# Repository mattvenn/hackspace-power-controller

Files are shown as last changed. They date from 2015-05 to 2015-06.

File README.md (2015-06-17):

# Hackspace machine access & usage logger

A system for allowing inducted users to turn power on to various machines. 

* Users are authenticated with RFID.
* Usage time is logged to a [google spreadsheet](https://docs.google.com/spreadsheets/d/1C3qdswIIFLBH4fQWuWFZRTpnnRjpzyk5xHRKnjuHExU/edit?usp=sharing).
* Inducted users are managed using the same spreadsheet.
* Tools are turned on and off with wireless mains plugs.

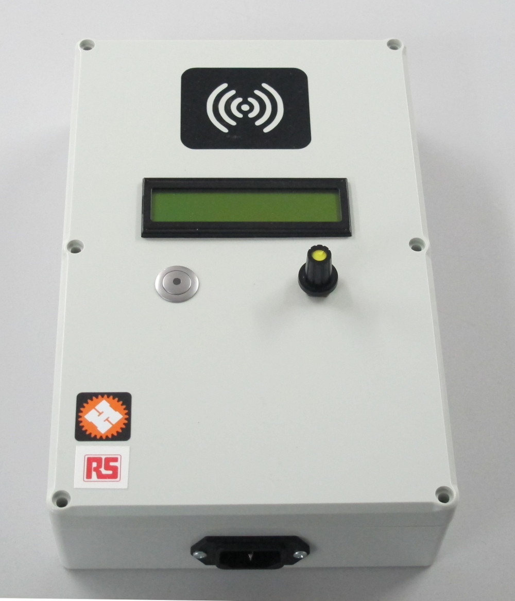
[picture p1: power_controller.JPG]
power controller


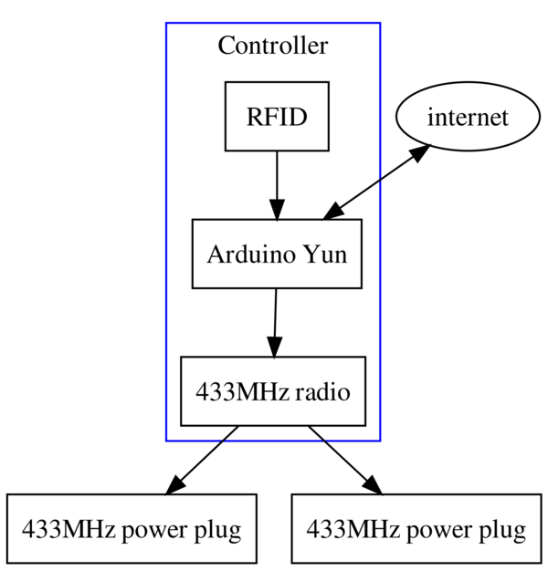
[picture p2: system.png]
system overview


Shortlink: [http://ven.nz/hkspcpc](http://ven.nz/hkspcpc)

Sponsored by [RS Components](http://uk.rs-online.com/web/)

## Pros

Cheap to implement as only need one central internet connected RFID reader and then very cheap
remote plugs for equipment.

Easy management for equipment managers via a google spreadsheet.

## Cons

Users will probably forget to 'log out' and clock up long machine run times.
Systems in use at [London
Hackspace](https://wiki.london.hackspace.org.uk/view/Project:Tool_Access_Control)
and [Nottingham Hackspace](https://wiki.nottinghack.org.uk/wiki/Nhtools) both
require the user's RFID card to remain in place while the machine is on, thus
making it less likely the user will leave the machine running.

Without covering/hacking the remote plugs; easy to bypass.

# Software

Split into:

* [Arduino code](software/power_controller/) for UI, RFID and radio. 
* [Python code](software/python/) for local caching, internet logging.

## Design decisions

* Presenting an inducted user's RFID card will authenticate.
* Simple menu system to scroll through available tools and start/stop them.
* Never switch off/time out the connected machine in case it's a long job.
* Allow an inducted user to end another user's session in case they left it
 running accidentally.
* Pull tools & validated users once per hour and store locally in case internet is unavailable.
* If internet is unavailable discard usage logging. Possible to add a queue later.

# Electrical

## Bill of Materials

See the [bom](electronics/bom.md)

## Schematic

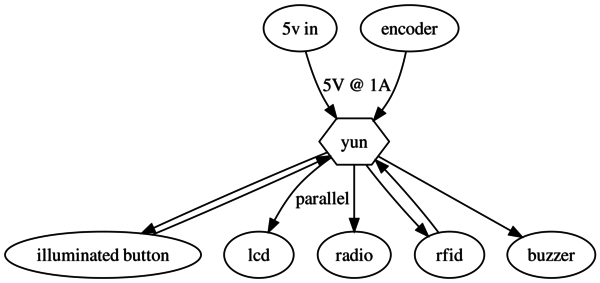
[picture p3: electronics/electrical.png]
electrical components and wiring


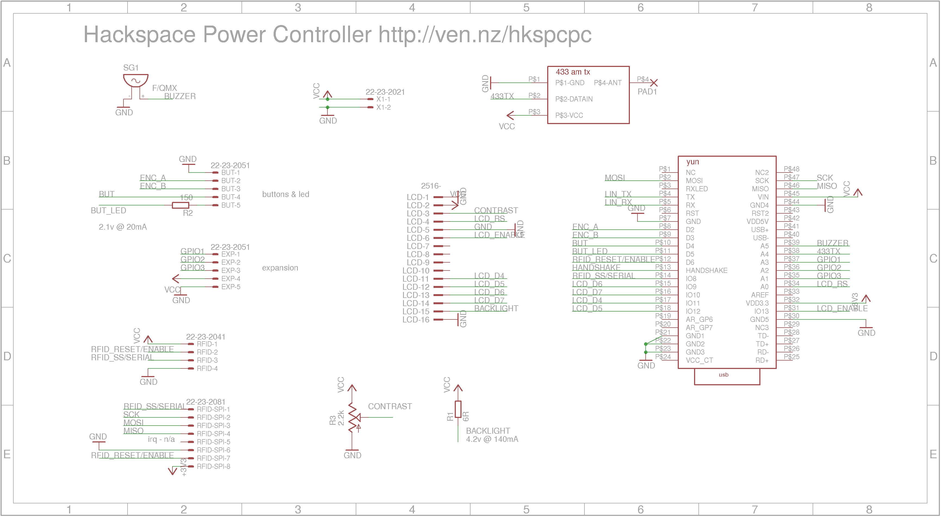
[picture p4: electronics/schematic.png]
schematic


[Eagle cad files](electronics) including [single layer PCB
layout](electronics/board.png)

## Case design

[Case design](case/case.md) [generated with openscad file case.scad](case/case.scad)

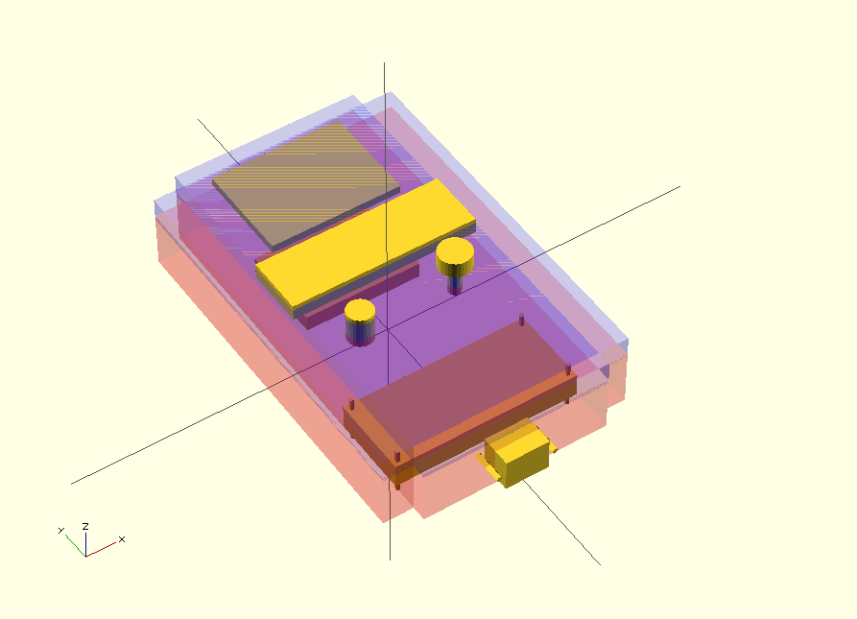
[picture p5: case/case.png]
case


# Project log

[Project log details design, build and testing](project_log.md)

[Photos](https://goo.gl/photos/4R67unRSMY9yUnsj8)

# Licenses

* Hardware is licensed under the [CERN open hardware license 1.2](http://www.ohwr.org/attachments/2388/cern_ohl_v_1_2.txt)

* Software is licensed under a Creative Commons Attribution 4.0 International License.

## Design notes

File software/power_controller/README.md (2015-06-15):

# UI State machine

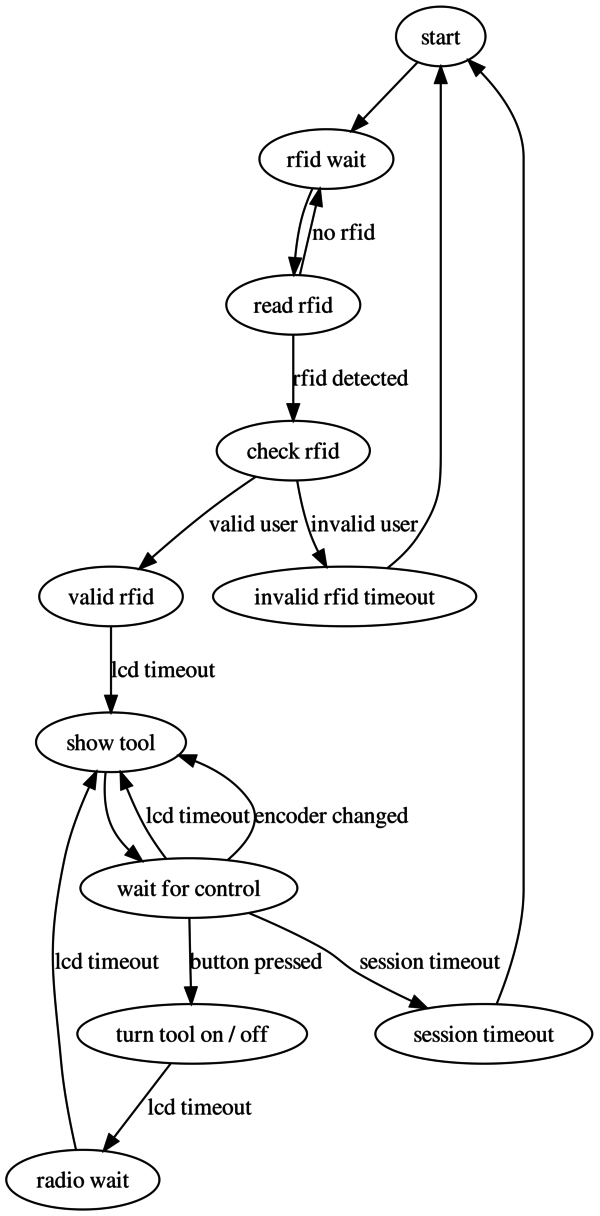
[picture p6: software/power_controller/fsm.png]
FSM diagram


# LCD Menu

[UI](ui.md)

# Arduino IDE

I had problems with an older version of the Arduino IDE compiler and Bridge
libraries. I had success with Arduino v1.6.4

# Requirements

Thanks to the developers of these libraries!

* [Rotary](https://github.com/brianlow/Rotary)
* [RFID](https://github.com/miguelbalboa/rfid) - only required for MFRC522
 reader
* [RCSwitch](https://github.com/sui77/rc-switch)

If you are using the Brennenstuhl sockets, then until my pull request is merged,
please use this [updated RCSwitch library](https://github.com/mattvenn/rc-switch).

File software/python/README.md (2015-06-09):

# Overview

query.py and post.py are required on the Yun. 
[setup instructions](setup.md)

## [query.py](query.py)

Called by the Arduino code using the [Bridge Process](http://www.arduino.cc/en/Reference/YunProcessConstructor)

Uses a local cache of tools and users to answer queries.

Runs post.py as a background process to do internet related tasks.

Logs to query.log

## [post.py](post.py)

Deals with all internet stuff:

* log tool usage
* post unrecognised rfid
* update local cache
* setup oauth2 tokens

Logs to post.log

# Debugging tools

## [log_serial.py](log_serial.py)

Helper script to log output of the Arduino and timestamp it for debugging

## [process_log.py](process_log.py)

Helper script to report number of cycles and cycle times of the debug logs

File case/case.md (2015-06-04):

# Case

[generated with openscad file case.scad](case.scad)

case

All measurements in mm and stated as L x W x D

* Yun + PCB = 70 x 85 x 10
* RFID = 62 x 82 x ?
* LCD = 37 x 116 x ?
* Buttons = 8 x 20

Modelling the layout led to a case size of 280 x 120 x 90mm.
But these dimensions didn't yield many cases! So I looked for some common sizes
and found some that were 240 x 120 x 100mm. Setting the openscad case dimensions
to these figures allowed me to move things about to check fit.

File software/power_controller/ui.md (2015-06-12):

# LCD messages & Menu

Menu is driven by a rotary encoder and an illuminated button.

Display after inactive for 5 seconds

    --------------------
    scan RFID to start
    ven.nz/hkspcpc

Unrecognised user.

    --------------------
    unrecognised RFID

user Matt recognised

    --------------------
    user: matt
    scroll for tools

next page - shows a tool ready to start

    --------------------
    1: lathe    
    start?

next page - showing Nic is already using machine for 1 hour 21 secs

    --------------------
    2: mill     nic
    noinduct    00:01:21

next page - showing router is currently unavailable

    --------------------
    3: router   
    offline 

next page - showing laser cutter in use, but not inducted

    --------------------
    4: laser    nic    
    stop?       00:01:21

next page - showing saw available for use

    --------------------
    5: saw      
    start?

start/stop button pressed - showing saw and option to stop

    --------------------
    5: saw      matt
    stop?       00:00:20

next page - showing option 1 again

    --------------------
    1: lathe    
    start?

## Beeper

Beep when:

* RFID is read
* Button is pressed

## LEDs

button illuminated when a choice is allowed

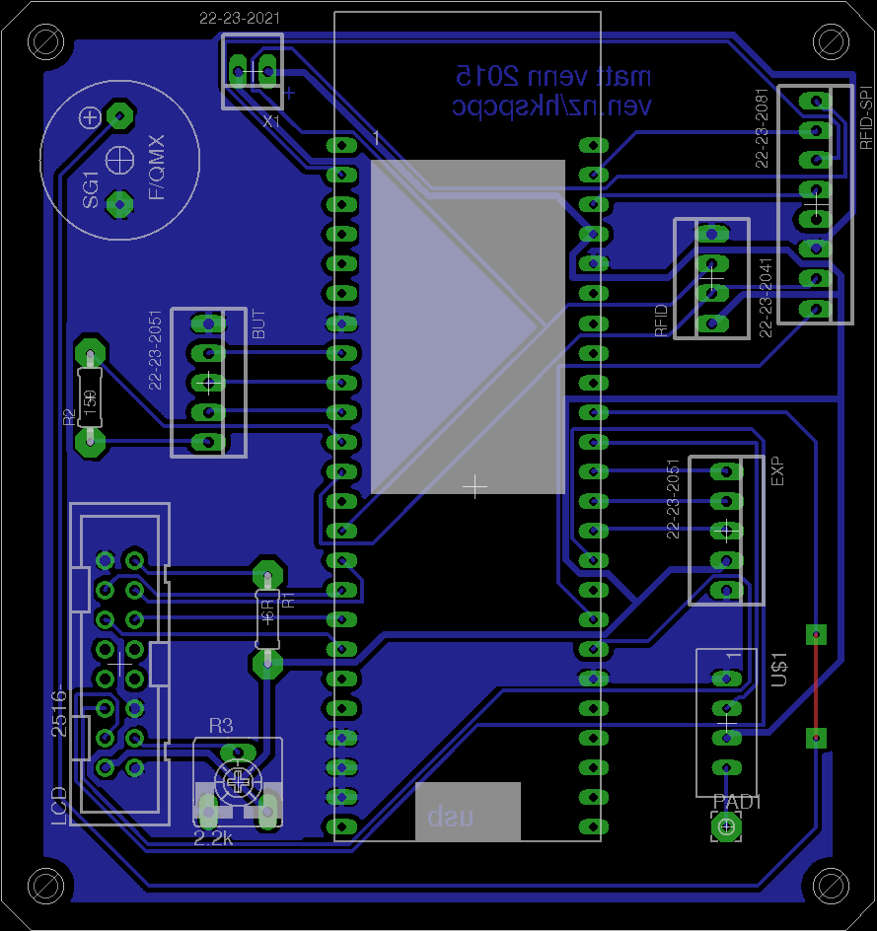
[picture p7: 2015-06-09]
electronics/board.png

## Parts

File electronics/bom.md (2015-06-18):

# Controller

* [Arduino Yun Mini]() - [datasheet](datasheets/Arduino-yun-mini-schematics.pdf)
* [RFID reader](http://uk.rs-online.com/web/p/products/6666625/) - [datasheet](http://docs-europe.electrocomponents.com/webdocs/0d16/0900766b80d1684b.pdf)
* [LCD 2x20](http://uk.rs-online.com/web/p/products/7200222/) - [datasheet](http://docs-europe.electrocomponents.com/webdocs/0f25/0900766b80f25e5b.pdf)
* [case 239](http://uk.rs-online.com/web/p/general-purpose-enclosures/3648043/) - [datasheet](http://docs-europe.electrocomponents.com/webdocs/1252/0900766b81252789.pdf)
* [433MHz ASK radio transmitter](http://uk.rs-online.com/web/p/lower-power-rf-modules/6172072/) - [datasheet](http://docs-europe.electrocomponents.com/webdocs/087d/0900766b8087d2df.pdf)
* [button](http://uk.rs-online.com/web/p/push-button-switches/7027226/)
 [datasheet](http://docs-europe.electrocomponents.com/webdocs/1259/0900766b812599cb.pdf)
* [encoder](http://uk.rs-online.com/web/p/mechanical-rotary-encoders/7295839/) - [datasheet](http://docs-europe.electrocomponents.com/webdocs/0f4c/0900766b80f4c3d5.pdf)
* m9x0.75 nut for encoder
* [buzzer](http://uk.rs-online.com/web/p/piezo-buzzer-components/5358253/)
* [psu](http://uk.rs-online.com/web/p/embedded-switch-mode-power-supplies-smps/7773109/)
* [iec inlet](http://uk.rs-online.com/web/p/iec-connectors/0488191/)

# Remote sockets

You will also need some remote sockets. I used [Brennenstuhl
3600](http://uk.rs-online.com/web/p/mains-connector-adapters-converters/7685368/)
from RS but I would recommend using something more compatible with the
[RC-Switch library](https://code.google.com/p/rc-switch/).

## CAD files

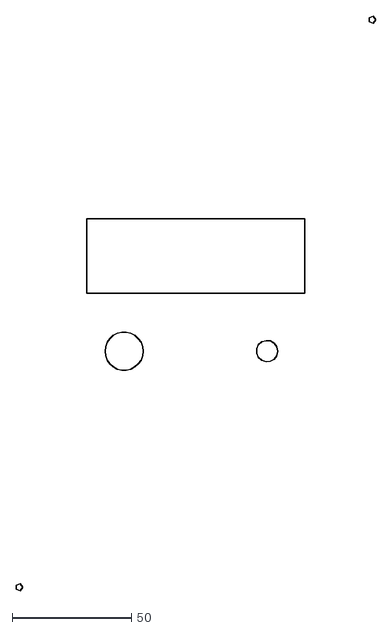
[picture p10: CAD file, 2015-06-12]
case/panel.dxf
150.7 x 240.9

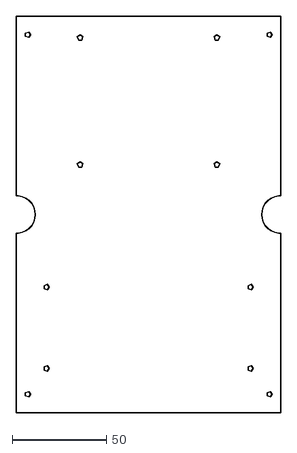
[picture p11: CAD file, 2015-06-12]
case/backpanel.dxf
140.0 x 210.0

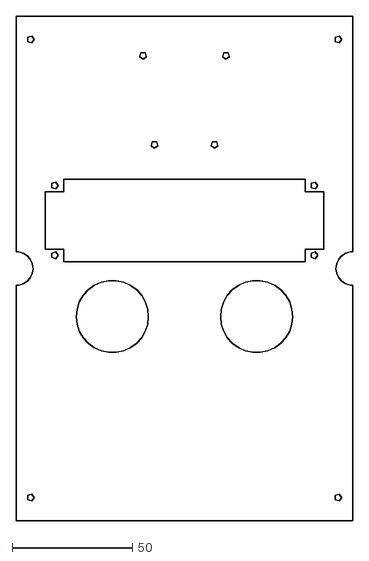
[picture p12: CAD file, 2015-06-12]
case/frontpanel.dxf
140.0 x 210.0

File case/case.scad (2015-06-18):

// make holes nice
$fa=10;
$fs=0.8;

// All measurements in mm and stated as L x W x D
// Yun = 73 x 53 x ?
yun_l = 75;
yun_w = 80;
yun_h = 15;
yun_b_l = 67.31;
yun_b_w = 72.39;

// IEC
iec_l = 27.5;
iec_w = 19.5;
iec_h = 25;
iec_bolt_d = 3.5;
iec_bolt_space = 40;

// psu
psu_l = 63.5;
psu_w = 45.7;
psu_h = 24;
// bolt spacing
psu_b_l = 57.15;
psu_b_w = 39.35;
psu_b_d = 4.0;


// button = 16mm diameter
button_d = 16;
button_h = 20; //including tabs

//encoder
encoder_d = 9;
encoder_h = 20;
encoder_knob_d = 20;
encoder_knob_h = 10;

// RFID = 62 x 82 x ?
rfid_l = 60;
rfid_w = 40;
rfid_h = 3;

// LCD = 37 x 116 x ?
lcd_l = 91.4;
lcd_w = 31.3;
lcd_h = 10;

// dimensions and names from the datasheet
case_a1 = 243.4;
case_a2 = 224.6;
case_b1 = 153.4;
case_b2 = 115.6;
case_c1 = 15;
case_c2 = 51;

screw_r = 1.5;

//uncomment these to make the DXFs
//projection() back_panel();
//projection() front_panel();
//projection()
//front_panel_mount();

complete();

//how it should look
module complete()
{
    //crappy way of putting it all together.
    translate([0,0,10])
    {
    translate([0,60,0]) rotate([0,0,90])yun();
    back_panel();
    translate([0,-60,0]) 
        psu();
    }
    translate([0,0,case_c2-10])
    {
        translate([0,70,-5]) rotate([0,0,-90]) rfid();
        front_panel_mount();
    }
    case();
    front_panel();
}

//the 3 mounting panels that we need
module back_panel()
{
    difference()
    {
        translate([0,0,-3]) mount_plate();
        // stuff on the base
        translate([0,60,0]) rotate([0,0,90])yun();
        translate([0,-60,0]) psu();
    }
}

module front_panel_mount()
{
    difference()
    {
        mount_plate();
        translate([0,70,-5]) rotate([0,0,-90]) rfid();
        translate([0,20,3]) lcd_mount();
        translate([0,-20,0])
        {
            translate([-30,0,0]) cylinder(r=15,h=10,center=true);
            translate([30,0,0]) cylinder(r=15,h=10,center=true);
        }
    }
}

module front_panel()
{
    // stuff on the lid
    case_holes(); //for alignment
    translate([0,0,case_c2])
    {
        translate([0,20,0]) lcd();
        translate([0,-20,0])
        {
            translate([-30,0,0]) button();
            translate([30,0,0]) encoder();
        }
    }
}

/***********************************************/
// modules

module iec()
{

    cube([iec_l, iec_w, iec_h], center=true);
    translate([-iec_bolt_space/2,0,0])
        cylinder(r=iec_bolt_d/2, h=iec_h, center=true);
    translate([iec_bolt_space/2,0,0])
        cylinder(r=iec_bolt_d/2, h=iec_h, center=true);
}

module yun()
{
    translate([0,0,yun_h/2])
    cube([yun_l, yun_w, yun_h], center=true);
    yun_b_d = 3.5;

    //fixings
    translate([-yun_b_l/2,-yun_b_w/2,yun_h/2])
        cylinder(r=yun_b_d/2, h=yun_h*2, center=true);
    translate([+yun_b_l/2,-yun_b_w/2,yun_h/2])
        cylinder(r=yun_b_d/2, h=yun_h*2, center=true);
    translate([+yun_b_l/2,+yun_b_w/2,yun_h/2])
        cylinder(r=yun_b_d/2, h=yun_h*2, center=true);
    translate([-yun_b_l/2,+yun_b_w/2,yun_h/2])
        cylinder(r=yun_b_d/2, h=yun_h*2, center=true);
}

module lcd_mount()
{
    translate([0,0,-lcd_h/2])
        cube([lcd_l*1.1, lcd_w*1.1, lcd_h], center=true);  
    //cut outs for the IDC connectors
    cube([116,24,lcd_h],center=true);
    b_l = 108;
    b_w = 29;
    b_h = 10;
    b_d = 3.5;
    translate([-b_l/2,-b_w/2,b_h/2])
        cylinder(r=b_d/2, h=b_h*2, center=true);
    translate([+b_l/2,-b_w/2,b_h/2])
        cylinder(r=b_d/2, h=b_h*2, center=true);
    translate([+b_l/2,+b_w/2,b_h/2])
        cylinder(r=b_d/2, h=b_h*2, center=true);
    translate([-b_l/2,+b_w/2,b_h/2])
        cylinder(r=b_d/2, h=b_h*2, center=true);

}
module lcd()
{
    translate([0,0,-lcd_h/2])
    cube([lcd_l, lcd_w, lcd_h], center=true);  
}

module psu()
{
    translate([0,0,psu_h/2])
    cube([psu_l, psu_w, psu_h], center=true);
    translate([-psu_b_l/2,-psu_b_w/2,psu_h/2])
        cylinder(r=psu_b_d/2, h=psu_h*2, center=true);
    translate([+psu_b_l/2,-psu_b_w/2,psu_h/2])
        cylinder(r=psu_b_d/2, h=psu_h*2, center=true);
    translate([+psu_b_l/2,+psu_b_w/2,psu_h/2])
        cylinder(r=psu_b_d/2, h=psu_h*2, center=true);
    translate([-psu_b_l/2,+psu_b_w/2,psu_h/2])
        cylinder(r=psu_b_d/2, h=psu_h*2, center=true);
}

//the small 13.5MHz one
module rfid()
{
    translate([-6,0,-rfid_h/2])
        cube([rfid_l, rfid_w, rfid_h], center=true);
    translate([-21,0,6])
        cube([30,26,rfid_h*2],center=true);

    b_l = 37;
    b_w1 = 34.5;
    b_w2 = 25.0;
    b_h = 10;
    b_d = 3.5;
    translate([-b_l/2,-b_w1/2,b_h/2])
        cylinder(r=b_d/2, h=b_h*2, center=true);
    translate([-b_l/2,+b_w1/2,b_h/2])
        cylinder(r=b_d/2, h=b_h*2, center=true);
    translate([+b_l/2,-b_w2/2,b_h/2])
        cylinder(r=b_d/2, h=b_h*2, center=true);
    translate([+b_l/2,+b_w2/2,b_h/2])
        cylinder(r=b_d/2, h=b_h*2, center=true);
}

module led()
{
    translate([0,0,-led_h/2])
    cylinder(r=led_d/2, h=led_h, center=true);
}

module button()
{
    translate([0,0,-button_h/2])
    cylinder(r=button_d/2, h=button_h, center=true);
}
module encoder()
{
    translate([0,0,-encoder_h/2])
    cylinder(r=encoder_d/2, h=encoder_h, center=true);
//   translate([0,0,encoder_h/2-encoder_knob_h/2])
//   cylinder(r=encoder_knob_d/2, h=encoder_knob_h, center=true);
}

module case_holes()
{
	w = 238;
	l = 148;
    bd = 1;
    translate([-l/2,-w/2,0])
        cylinder(r=bd/2, h=10, center=true);
    translate([+l/2,+w/2,0])
        cylinder(r=bd/2, h=10, center=true);
}

module mount_plate()
{
    mp_w = 191.0;
    mp_l = 128;
    mp_bd = 3.5;
    cut_r =8;
    w = 210;
    l = 140;
    difference()
    {
        cube([l,w,3],center=true);
        translate([l/2,0,0])cylinder(r=cut_r,h=10,center=true);
        translate([-l/2,0,0])cylinder(r=cut_r,h=10,center=true);
        translate([-mp_l/2,-mp_w/2,0])
            cylinder(r=mp_bd/2, h=10, center=true);
        translate([+mp_l/2,-mp_w/2,0])
            cylinder(r=mp_bd/2, h=10, center=true);
        translate([+mp_l/2,+mp_w/2,0])
            cylinder(r=mp_bd/2, h=10, center=true);
        translate([-mp_l/2,+mp_w/2,0])
            cylinder(r=mp_bd/2, h=10, center=true);
    }
}

module case()
{
	rotate([0,0,90])
    {
        color("red", 0.4)
        translate([0,0,(case_c2-case_c1)/2])
        {
            cube([case_a1, case_b2, case_c2-case_c1], center=true);
            cube([case_a2, case_b1, case_c2-case_c1], center=true);
        }
        color("blue", 0.4)
        translate([0,0,case_c2/2-15 + case_c1 *2 ])
        {
            cube([case_a1, case_b2, case_c1], center=true);
            cube([case_a2, case_b1, case_c1], center=true);
        }
    }
}

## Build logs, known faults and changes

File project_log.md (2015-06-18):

# Todo

* More testing on Yun Mini Wifi

# 2015/06/16

The Yun Mini finally arrived! So these notes will be about the differences I
discover in getting the software to work on it.

* password/login screen has changed, and the password is doghunter
* the hostname has changed to linino.local
* uname -a now is Linux linino 3.3.8 #1 Sat Apr 18 02:45:58 CEST 2015 mips GNU/Linux
* no package python-ssl, tried python-openssl, works
* no python package atom, copied from my laptop (added to gdata.tar.gz)

Things that didn't work:

* Button [didn't work as expected](http://www.mattvenn.net/2015/06/18/57m-ss-hall-effect-button/)!
* PSU wrong! I've got no idea how I managed to get this wrong after spending so
 much time on it. It only goes up to ~120VAC. I've changed the BOM already.
* My Yun Mini PCB footprint slightly wrong sized, but still fits!
* My Yun Mini has poor wifi abilities, can't reliably create a hotspot or stay connected to another network.

# 2015/06/12

Nice day in the workshop building the [case](case/case.scad). Even made a vinyl
cut sticker to show where the RFID tag is swiped.
Laser cut the mounting panels for inside the box, and used the CNC router for
the front panel. Had to dremel the IEC inlet because the box is tool tall to fit
in the machines.

[Bubble etched](http://bristol.hackspace.org.uk/wiki/doku.php?id=bubble-etch) the PCB. I know it's not really necessary but I'm a sucker for
neatness inside the box as well as outside!

Had a chat with Nic about usage, and he reckons that requiring people to log
out will be problematic. Within the scope of this project I can't do much about
that. I do like the London and Nottingham hackspace systems that require an RFID
card left in a box by the machine in use.

I've modified the software so that a new user can stop another user's running
session in case they've left a machine running accidentally.

It's an interesting part of this project - normally I have a set idea I'm
working to and then if I make a mistake with a part I can change it. This time,
I'm working with a specific part, and then if later I realise the idea doesn't
quite fit I'd have to change the idea. Not going to do that after all this work
though!

# 2015/06/09 Lessons learnt (again)

* Just because I've seen a problem before doesn't mean I'll recognise it again
* Interprocess communication is harder than it seems
* When debugging problems with processes ending on Linux, keep a log of load avg
 and memory usage
* When making major changes to [the plan](#multiprocess), spend time thinking of
 the ramifications - pretty obvious what was going to happen in hindsight.

# 2015/06/06 Bridge.py problems

On another long burn test I got bridge.py to crash again. Once it's dead then
it's game over for the whole system. This time I was logging everything and I
found something interesting. Just before the system stopped I got a connection
timeout from post.py (logging to internet). In the meantime another 2 logging
processes were started (before the first post.py timed out). So 3 in total, plus the query program that calls it.

I [found a good way to spoof a
timeout](http://stackoverflow.com/questions/100841/artificially-create-a-connection-timeout-error)

Then I ran a simple Arduino program to call query.py which in turn starts a new
process (post.py) that will get timed out. After 4 loops the Yun became
unresponsive. I got a chance to run loadavg and look at /proc/meminfo:

    20:10:58 up  8:01,  load average: 2.31, 1.01, 0.47

    root@Arduino:~# cat /proc/meminfo 
    MemTotal:          61116 kB
    MemFree:            1356 kB

I'm guessing that as memory ran out, oom killer started killing big memory hogs,
which includes bridge.py (13% of total RAM, oom_score=45).

It's funny because I've come across this exact issue before with a script
executed with a cronjob - fixed with a lock. And I'd put adding a lock to
post.py on the todo list, but didn't get round to it. Instead I've spent hours researching a
problem that wouldn't have happened if I'd added the lock in the first place!

I tried to get the oom killer to do it's thing by running lots of processes but
it never seemed to come into life. After enough processes the Yun hung and I had
to reboot it. Fingers crossed this is the issue and it's now solved.

After a night of running the `Tool log - read rfid, fetch user, log tool to
internet` test I clocked up 5600 cycles and everything stayed running.

# Burn testing

Lots of cycles of the parts of the code that use the bridge code:

* fetching user info
* logging unknown rfid to internet
* fetching tools
* logging tool user to internet

## Unknown rfid - read rfid, fetch user, log to internet

3500 cycles in 8 hours, 11 cycles were longer than 5 seconds.
Mem checks:

    root@Arduino:~# cat /proc/meminfo | head
    MemTotal:          61116 kB
    MemFree:           29244 kB

Uptime checks

    20:02:51 up  3:16,  load average: 1.48, 1.65, 1.75

## Known rfid - read rfid, fetch user, return

1000 cycles in 1:10, all cycles completed in less than 4 secs

    21:22:26 up  4:36,  load average: 1.33, 0.72, 0.57

## Tool log - read rfid, fetch user, log tool to internet

Just when I thought it was safe to celebrate I started getting this:

    from: 06-05 07:48:42 about to run   
    to  : 06-05 07:49:18 finished        took 36.0 secs
    from: 06-05 07:49:44 about to run   
    to  : 06-05 07:50:21 finished    

Starting at 00:21:00 and continuing for every bridge process call after. Looking
at the logs for the query.py program and the post.py program I could see that
neither had been called since that time. So something happened to the bridge
program that made it unable to call programs.

I added some log lines to the Yun's bridge.py and processes.py programs to help
debug this. Now I'm getting lines like this in ~/bridge.log:

    06-05 09:17:46 INFO     starting process [['/root/query.py', '--check-user', '--rfid', '04184A4FC6']]
    06-05 09:17:46 INFO     process id is 0
    06-05 09:17:49 INFO     waiting for process 0
    06-05 09:17:49 INFO     finished 0

So at least I'll be able to see what the process call was before bridge gets
killed. Just setup another identical test and will leave all day.

# 2015-06-04 - Even More Testing

Still investigating the hangs. Got another program called
[process_log.py](software/python/process_log.py) that reads the log lines and
reports any pair of lines that are more than a set number of seconds apart.
That's been useful in helping to identify which parts of the code are hanging.

This test was with an invalid rfid card on top of the reader. It shows that the code is sometimes taking 30 seconds to read the rfid.

    from: 06-04 08:34:23 finished       
    to  : 06-04 08:34:53 rfid available  took 30.0 secs

And here's some logs showing what happens when the arduino code checks the rfid
with the cached users using query.py:

    from: 06-03 08:35:52 about to run   
    to  : 06-03 08:38:45 finished        took 173.0 secs
    from: 06-03 08:46:04 about to run   
    to  : 06-03 08:47:11 finished        took 67.0 secs

And here's the log from the python program at the same time:

    06-03 08:35:55 WARNING  logging unknown rfid [04184A51EB]
    06-03 08:35:55 INFO     ending
    06-03 08:38:53 WARNING  logging unknown rfid [04184A51EB]
    06-03 08:38:53 INFO     ending

I can see the program starting and ending straight away, but the code on the
arduino is hanging for around 3 minutes!
So I'm assuming the problem is with the Process stuff on the Arduino or the bridge.py program on the Yun.

I just updated the arduino ide from 1.5.8 to 1.6.4. Looking at the md5sums of
the source for the Bridge stuff, I can see that Bridge.cpp has changed but
Process.cpp hasn't. There is a change in put() which I don't think is being
used, but another in transfer to do with buffer lengths, so perhaps that's
hopeful.

Setting exit(1) in query.py for unknown users seems to have helped with the long
hang times related to looking up user. The update to arduino ide 1.6.4 made a
big difference to long timeouts occuring randomly to all bridge process
requests.

# 2015-06-03 - More Testing

As always, it's fairly quick to put together something that sort of works. But
then finding all the little bugs and issues that have to be ironed out to make a
good reliable product takes a lot longer.

To help me test it I put together a [useful little
script](software/python/log_serial.py) to capture and time
stamp the logging from the Arduino part of the Yun.

The system has been running over night and I've collected logs from the Linux
and Yun side of things (timestamps synced courtesy of ntp).

The only issue so far is occasional minute long hangs with the Process.run()
Arduino code. After all the hassle with getting things working in the first
place I'm going to leave this un-investigated for now. If people are interested
in the project then it can be fixed then.

# 2015-06-02 - Testing

During testing I discovered a nasty bug where the bridge.py process on the yun
(that deals with linux<->arduino communication) was failing. After a lot of
debugging (I thought it was to do with stderr buffers being overflowed) I
finally discovered that I wasn't null terminating the formatted time string for
tool logging.

## Multiprocess

There are 3 times when the system needs to connect to the internet:

* updating cache of users and tools
* logging unknown rfids
* logging tool usage when a tool is turned off

I don't want the UI to hang while these are happening. Although the Yun bridge
library has support for running shell commands asyncronously I decided to do it
on the Linux side.

I split the fetch program into [query](software/python/query.py) and
[post](software/python/post.py). 

query is what the Arduino uses for all user info/logging requests. It necessary
it then runs the post command as a subprocess that runs separately.

# 2015-06-01 - Testing

Nice day of tidying things up and testing. Decided to put all the config data in
one spreadsheet - tool owners/responsible people will have to trust each other.

Remember to doc some spreadsheet gotchas:

* tool ids have to be 1 indexed, as 0 is invalid (software bug with parseInt returning 0 for no parse)
* max tools is 10 (firmware)

Wanted to do async running of shell command but it doesn't seem to work. Not
investigating further for now.

# 2015-05-31 - Google doc access on the Yun with Python

Finally found a way of doing oauth2 with python without the google oauth2.client
library that has too many dependencies: gdata. This is another google library
for interacting with the google apis. It has built in oauth2 client and can be
installed on the yun:

    wget https://pypi.python.org/packages/source/g/gdata/gdata-2.0.18.tar.gz#md5=13b6e6dd8f9e3e9a8e005e05a8329408 --no-check-certificate

    tar -xzf gdata-2.0.18
    cd gdata-2.0.18
    python setup.py install

This package needs python expat installed:

    opkg install python-expat

## Oauth2 stuff:

* setup a new client id of type 'service account' in https://console.developers.google.com
* download json and save to secrets.json
* run ./fetch.py --auth-token
* follow the url, then tokens will be added and saved to secrets.json

# 2015-05-30 - Temboo

Testing Yun cloud stuff. Temboo seems cool, but the only way to get columns of
data seems to be using a json or xml based fetch. Fetching 100 rows of user info
ended up being 200k of json! 

Made a help request and very quickly got told about adding output filters like
this:

    RetrieveSpecificRowsOrColumnsChoreo.addOutputFilter("users", "/entry[]/content","Response");

Which filters that 200k down to just the bits I need. So that's looking good.
The problem though is that my menu/rfid/lcd stuff is taking about 13k (60%) of
program space on the Yun. The Temboo demo for just fetching the user names comes
out at 13k (45%). So even with the output filtering I don't think the program
size is feasible.

So...
Now looking into a python script that does the spreadsheet stuff and can be
called via the bridge library. It could fetch all users and then cache them to
disk making subsequenct calls fast.

Got [something working](software/spreadsheet/fetch.py) so wanted to test on Yun. OpenWRT doesn't come with pip or
openssl, so with some [googling found
this](http://samjbrenner.com/notes/using-pip-to-install-python-packages-on-the-arduino-yun/).

Pip installed ok though I was amazed at the amount of disk it needs. The Yun
only has about 6.6MB for playing with, so it will be hard to get all these
packages installed.

I'm trying to avoid pip now and install things from downloaded packages, and
using opkg as much as possible. 

The stumbling block now is getting the python ssl stuff working. Most of it
seems to install ok, but it has a dependency on cffi. This seems to need to be
compiled and of course the Yun doesn't come with a compiler...

Trying an older version of oauth2client 1.4.3, still uses pyOpenSSL which has
the cffi dependency.

# 2015-05-29 - Peripheral hacking

Train hacking! Got LCD, RFID, encoder and button working on the train up to
Leeds.

# 2015-05-28 - AM switch control with RC-Switch

Had a look at 13.56MHz RFID readers and common (cheap) readers are all SPI and
3.3v. So I might change the PCB layout to accomodate either the serial or SPI
versions. 

[Cheap RFID/NFC reader for 13.56MHz based on
MFRC-522](http://www.ebay.co.uk/itm/261899995126)

[Image of RFID reader
pins](http://4.bp.blogspot.com/-CypWJHefOgY/U9AnzSpeEyI/AAAAAAAABao/fZKUC4YPNRk/s1600/RFID-RC522-pinout.png)

[Library](https://github.com/miguelbalboa/rfid), supports different SS & Reset
pins.

Not sure about availability of SPI for Yun though, is it used for the
bridge?

[Yun spec](http://www.arduino.cc/en/Main/ArduinoBoardYun) says:

* can handle SPI, though pins are connected to the wifi module
* pins 0&1 used for bridge serial comms so avoid

So will add header, using SS & Reset as the pins I'm using for the serial RFID's
enable & data.

# 2015-05-27 - Components arrive

Received the components for testing. For all part numbers and datasheets see the
[bom.md](bom.md)

## Wireless plugs

The only remote plugs RS carry are the brennenstuhl 3600. These operate at
433MHz using AM. I was able to see the codes using a receiver module and a
scope. However RCSwitch doesn't seem to work easily. With some measurement and
copying down of 24bit codes from the scope I got the plugs switching with the
little AM transmitter I'll be using.

However the units seem to use some weird kind of unrepeating code that makes it
harder than I'd like to add more units. Found this [forum
thread](http://forum.pilight.org/Thread-Brennenstuhl-RC-3600) with more info,
but no solution. It works well enough for a demo but I wouldn't recommend these
units for home automation.

Found this [list of codes](http://pastebin.com/RgQ4VCyw), which I've yet to
compare against the 3 that I've decoded.

## LCD

20x2 line standard LCD. Worked as expected.

## RFID

I was expecting the RFID reader to read my hackspace access pass but it didn't.
I know there are 2 main bands: 125KHz and 13.56MHz. The reader is 125KHz type. I
suppose my card is the other, or that there are sub divisions of communication
types. I have ordered some 125KHz tags for now and am investigating the cards we
use for the hackspace.

## Rotary encoder

I was initially thinking of using just 2 illuminated buttons. But I wanted to the option to
use a rotary encoder in case that makes things more intuitive. I got a 12
position detented type to test.

Used an Adafruit library (see [requirements.txt](code/requirements.txt)) to read
the encoder. This works as expected.

# 2015-05-22 - Research

Got the Yun schematic so I could start thinking about pinouts. I'm thinking of
making a simple, single sided PCB to keep things neat. Necessary?

Worked out how much money the project cost and thought it was too high to be
practical for anyone else. Had the idea of using wireless mains plugs. This
means the control box can be safer & cheaper - plus have the option to control
many more machines.

Initial research:

* http://hackaday.com/2013/01/31/getting-an-arduino-to-control-a-wireless-outlet/
* https://code.google.com/p/rc-switch/
* https://code.google.com/p/rc-switch/wiki/List_KnownDevices
* http://www.maplin.co.uk/p/remote-controlled-mains-sockets-set-3-pack-n79ka
* http://www.instructables.com/id/Home-Automation-or-Robot-Butler-called-Geoffrey-/

RC-Switch library looks interesting. Have asked RS if they have anything
compatible.

# 2015-05-13 - Initial design

Initial design for a single enclosed RFID controlled switch. I chose a SSR for
simplicity.

Difficult to find a small panel mounted PSU for the power I require. Best I
could do was a 10W supply, which is much higher than needed.

Enjoyed using [visgraph](http://www.graphviz.org/) for the first time!

Modelled the components in openscad and moved things around to get the switched
mode PSU and Yun on opposite sides (hoping to reduce radio interference).

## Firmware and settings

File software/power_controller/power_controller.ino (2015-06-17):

//pin defs
#define ENC_A 3
#define ENC_B 2
#define BUT 4
#define BUT_LED 5

//either define RFID_SERIAL (serial based 125khz reader) or RFID_SPI (RC522 SPI based 13Mhz reader)
//#define RFID_SERIAL
#define RFID_SPI

#ifdef RFID_SERIAL
	#define RFID_NOT_ENABLE 6
	// Not all pins on the Leonardo support change interrupts,
	// so only the following can be used for RX:
	// 8, 9, 10, 11, 14 (MISO), 15 (SCK), 16 (MOSI).
	#define RFID_RX 8
    #define RFID_TX RFID_RX //same as each other as we never send
#elif defined RFID_SPI
	#define SS_PIN 8
	#define RST_PIN 6
#endif

#define HANDSHAKE 7 //do not use - reserved for future use?

//lcd
#define LCD_D6 9
#define LCD_D7 10
#define LCD_D4 11
#define LCD_D5 12
#define LCD_EN 13
#define LCD_RS A0

#define RADIO_TX A4
#define BUZZ A5

//unused pins broken out to GPIO header
#define GPIO1 A3
#define GPIO2 A2
#define GPIO3 A1

#include <LiquidCrystal.h>
#include <Process.h>

//UI defs
#define LCD_TIMEOUT 1000 //time we spend before changing screen
#define SESSION_TIMEOUT 5000 //time before session times out
#define RFID_INVALID_TIMEOUT 4000 //time before we scan again after bad rfid
#define MAX_TOOLS 3 //you must have this many radio codes defined in radio.ino
#define TOOL_UPDATE_PERIOD 1800000 //ms in half an hour

//LCD
LiquidCrystal lcd(LCD_RS, LCD_EN, LCD_D4, LCD_D5, LCD_D6, LCD_D7);

//FSM states
#define S_START 0
#define S_WAIT_RFID 1
#define S_READ_RFID 2
#define S_CHECK_RFID 3
#define S_RFID_VALID 4
#define S_RFID_INVALID 5
#define S_WAIT_CONTROL 6
#define S_LCD_SHOW_TOOL 7
#define S_TIMEOUT 8
#define S_START_TOOL 9
#define S_STOP_TOOL 10
#define S_WAIT_RADIO 11

//array of tool data
struct tool
{
    String name;
    bool running = false;
    String current_user = "";
    String current_rfid = "";
    bool operational = true;
    int time = 0;
    int id = 0; //0 is an invalid id
} tools[MAX_TOOLS];

//authenticated user's info
struct user
{
    String name = "";
    String rfid = "";
    int tools[MAX_TOOLS];
    int timeout = 0;
} user;

//ui globals
int fsm_state_user = S_START;
int enc_clicks = 0; //encoder enc_clicks
int page_num = 0; //what page is showing on lcd
String rfid; //where rfid tags are read into
int num_tools = 0;
unsigned int state_timer = 0; //counter for states
String query_cmd = "/root/query.py"; //what we use to query users/log tool time
unsigned long int last_updated_tools = 0;


void setup()
{
    Serial.begin(9600); 
    Serial.println(F("started"));

    //peripherals
    setup_lcd();
    setup_radio();
    setup_rfid();

    //button setup
    pinMode(BUT, INPUT);
    digitalWrite(BUT, HIGH);
    pinMode(BUT_LED, OUTPUT);
    digitalWrite(BUT_LED, LOW);

    //initialize the Bridge, takes a few seconds
    lcd_boot_screen();
    Bridge.begin();

    //fetch users & tools
    num_tools = get_tools();
}

void loop() 
{
    switch(fsm_state_user)
    {
        case S_START:
            lcd_start();
            start_rfid();
            fsm_state_user = S_WAIT_RFID;
            state_timer = 0;
            break;
        
        case S_WAIT_RFID:
            if(state_timer >= 50)
                fsm_state_user = S_READ_RFID;
            break;

        case S_READ_RFID:
            rfid = read_rfid();
            if(rfid != "")
                fsm_state_user = S_CHECK_RFID; 
            else
            {
                state_timer = 0;
                fsm_state_user = S_WAIT_RFID;
            } 
            break;

        case S_CHECK_RFID:
            lcd_check_rfid();
            tone(BUZZ,1500,100);
            //check python command via bridge
            if(auth_user(rfid))
            {
                Serial.println(F("valid id"));
                tone(BUZZ,1500,100);
                delay(150);
                tone(BUZZ,1500,100);
                state_timer = 0;
                page_num = 0;
                enc_clicks = 0;
                fsm_state_user = S_RFID_VALID;
                lcd_valid_user();
            }
            else
            {
                fsm_state_user = S_RFID_INVALID;
                tone(BUZZ, 500, 500);
                state_timer = 0;
                lcd_invalid_user();
            }
            break;

        case S_RFID_VALID:
            if(state_timer >= LCD_TIMEOUT)
                fsm_state_user = S_LCD_SHOW_TOOL;
            break;

        case S_RFID_INVALID:
            if(state_timer >= RFID_INVALID_TIMEOUT)
                fsm_state_user = S_START;
            break;

        case S_WAIT_CONTROL:
        {
            //update lcd as soon as encoder changes
            if(encoder_changed())
            {
                fsm_state_user = S_LCD_SHOW_TOOL;
                digitalWrite(BUT_LED, LOW);
                state_timer = 0;
                user.timeout = 0;
            }
            //button press logic, only allow inducted users to do things
            if(button_pressed())
            {
                state_timer = 0;
                user.timeout = 0;

                //only if tool operational
                if(tools[page_num].operational)
                    if(is_inducted(tools[page_num].id))
                        if(tools[page_num].running)
                        {
                            //this line means only the person 
                            //who started the tool can stop it.
                            //if(tools[page_num].current_user == user.name)
                            fsm_state_user = S_STOP_TOOL;
                        }
                        else
                            fsm_state_user = S_START_TOOL;
            }            
                            
            //update lcd regularly
            if(state_timer >= LCD_TIMEOUT)
                fsm_state_user = S_LCD_SHOW_TOOL;

            //if user doesn't do anything for long enough, time out 
            if(user.timeout >= SESSION_TIMEOUT)
            {
                Serial.println(F("auth timeout"));
                fsm_state_user = S_TIMEOUT;
                digitalWrite(BUT_LED, LOW);
                timeout_user();
                state_timer = 0;
                lcd_session_timeout();
                tone(BUZZ, 500, 500);
            }
            break;
        }
        case S_LCD_SHOW_TOOL:
            lcd_show_tool_page();
            fsm_state_user = S_WAIT_CONTROL;
            state_timer = 0;
            break;

        case S_START_TOOL:
            digitalWrite(BUT_LED, LOW);
            state_timer = 0;
            lcd_wait_radio_on();
            start_tool();
            fsm_state_user = S_WAIT_RADIO;
            break;

        case S_STOP_TOOL:
            digitalWrite(BUT_LED, LOW);
            state_timer = 0;
            lcd_wait_radio_off();
            stop_tool();
            fsm_state_user = S_WAIT_RADIO;
            break;

        case S_WAIT_RADIO:
            if(state_timer >= LCD_TIMEOUT)
                fsm_state_user = S_LCD_SHOW_TOOL;
            break;
            
        case S_TIMEOUT:
            if(state_timer >= LCD_TIMEOUT)
                 fsm_state_user = S_START;
            break;
            
    }

    //FSM time keeping
    delay(1);
    if(state_timer < 0xFFFF)  // Don't let the state_timer overflow
    {
        state_timer++;
        user.timeout++;
    }
/*
    //Update tool table regularly
    if(millis() > last_updated_tools + TOOL_UPDATE_PERIOD)
    {
        //only update if no one using tools right now
        if(can_update_tools())
        {
            Serial.println(F("updating tools"));
            num_tools = get_tools();
            last_updated_tools = millis();
        }
    }
    */
}
        
bool encoder_changed()
{
    //check encoder - could use interrupts instead of polling
    check_encoder();

    //limit to num of tools available & wrap around
    if(enc_clicks < 0)
        enc_clicks = num_tools -1;
    if(enc_clicks > num_tools - 1)
        enc_clicks = 0;
    
    //different to last time? update display
    if(page_num != enc_clicks)
    {
        page_num = enc_clicks;
        tone(BUZZ,2000,50);
        return true;
    }
    else
        return false;
}

bool button_pressed()
{
    //check button
    if(digitalRead(BUT) == LOW)
    {
        //debounce
        while(digitalRead(BUT) == LOW);
        tone(BUZZ,1000,100);
        return true;
    }
    else
        return false;
}

//memory tracking
/*
extern unsigned int __data_start;
extern unsigned int __data_end;
extern unsigned int __bss_start;
extern unsigned int __bss_end;
extern unsigned int __heap_start;
extern void *__brkval;

int free_memory() {
    int free_memory;
  
    if((int)__brkval == 0)
        free_memory = ((int)&free_memory) - ((int)&__bss_end);
    else
        free_memory = ((int)&free_memory) - ((int)__brkval);
    return free_memory;
};
*/

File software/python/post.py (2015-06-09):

#!/usr/bin/env python
'''
read setup.md for info in getting oauth2 setup. 

gspread docs:
http://gspread.readthedocs.org/en/latest/oauth2.html
https://gdata-python-client.googlecode.com/hg/pydocs/gdata.spreadsheets.client.html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
'''
import json
import argparse
import logging
from logging.handlers import RotatingFileHandler
from datetime import datetime
import gdata.spreadsheets.client
import gdata.gauth
import fcntl
import socket
from query import get_install_dir, get_user, get_users_file, get_tools_file

log = logging.getLogger('')


def get_secrets_file():
    return get_install_dir() + "/secrets.json"

def load_secrets():
    with open(get_secrets_file()) as fh:
        secrets = json.load(fh)
    return secrets

def get_tokens():
    secrets = load_secrets()
    token = gdata.gauth.OAuth2Token(
        client_id=secrets["installed"]['client_id'],
        client_secret=secrets["installed"]['client_secret'],
        scope='https://spreadsheets.google.com/feeds/',
        user_agent=__name__)

    log.info(token.generate_authorize_url())
    code = raw_input('click the above link, then paste the code here: ').strip()
    token.get_access_token(code)
    secrets["refresh_token"] = token.refresh_token
    secrets["access_token"] = token.access_token
    secrets['spread_key'] = args.spread_key

    with open(get_secrets_file(),'w') as fh:
        json.dump(secrets, fh)
        log.info("wrote refresh and access token to secrets.json")

def get_client():
    secrets = load_secrets()
    try:
        token = gdata.gauth.OAuth2Token(
            client_id=secrets["installed"]['client_id'],
            client_secret=secrets["installed"]['client_secret'],
            scope='https://spreadsheets.google.com/feeds/',
            user_agent=__name__,
                access_token=secrets['access_token'],
                refresh_token=secrets['refresh_token'])
    except KeyError as e:
        log.error("you must do oauth2 setup first - read the setup.md file")
        exit(1)

    client = gdata.spreadsheets.client.SpreadsheetsClient()
    token.authorize(client)
   
    return client, secrets['spread_key']

def worksheet_dict(feed):
    d = {}
    for i, entry in enumerate(feed.entry):
        d[entry.title.text] = entry.id.text.split('/')[-1] 
    return d

def fetch_tools():
    log.debug("fetching tools")
    client, spread_key = get_client()
    sheets = worksheet_dict(client.get_worksheets(spread_key))
    worksheet_id = sheets['tools']
    all_tools = []
    for entry in client.get_list_feed(spread_key, worksheet_id).entry:
        all_tools.append(entry.to_dict())
    log.info("fetched %d tools" % len(all_tools))
    with open(get_tools_file(), 'w') as fh:
        json.dump(all_tools, fh)

def fetch_users():
    log.debug("fetching users")
    client, spread_key = get_client()
    sheets = worksheet_dict(client.get_worksheets(spread_key))
    worksheet_id = sheets['users']

    all_users = []
    for entry in client.get_list_feed(spread_key, worksheet_id).entry:
        all_users.append(entry.to_dict())

    log.info("fetched %d users" % len(all_users))
    with open(get_users_file(), 'w') as fh:
        json.dump(all_users, fh)

def log_unknown_rfid(rfid):
    log.info("logging unknown rfid [%s]" % rfid)
    client, spread_key = get_client()
    sheets = worksheet_dict(client.get_worksheets(spread_key))
    worksheet_id = sheets['unknown']
    entry = gdata.spreadsheets.data.ListEntry()
    entry.set_value('rfid', rfid)
    entry.set_value('date', str(datetime.now()))
    client.add_list_entry(entry, spread_key, worksheet_id)

def log_time(tool, time, name, rfid):
    log.info("logging %s on %s for user %s [%s]" % (time, tool, name, rfid))
    client, spread_key = get_client()
    sheets = worksheet_dict(client.get_worksheets(spread_key))
    try:
        worksheet_id = sheets[tool]
    except KeyError:
        log.error("no such tool in spreadsheet")
        exit(1)

    entry = gdata.spreadsheets.data.ListEntry()
    entry.set_value('rfid', rfid)
    entry.set_value('name', name)
    entry.set_value('date', str(datetime.now()))
    entry.set_value('time', time)
    client.add_list_entry(entry, spread_key, worksheet_id)


if __name__ == '__main__':

    parser = argparse.ArgumentParser(description="yun spreadsheet interface")
    parser.add_argument('--auth-token', action='store_const', const=True,
        help="do oauth2 token stuff")
    parser.add_argument('--spread-key', action='store',
        help="store the spreadsheet key")
    parser.add_argument('--update-cache', action='store_const', const=True,
        help="refresh the user and tool cache")
    parser.add_argument('--rfid', action='store',
        help="rfid")
    parser.add_argument('--time', action='store',
        help="specify time to log")
    parser.add_argument('--log-tool', action='store',
        help="log a tool usage")
    parser.add_argument('--log-unknown-rfid', action='store_const', const=True,
        help="log an unknown user")

    # setup logging
    log.setLevel(logging.DEBUG)
    log_format = logging.Formatter("%(asctime)s - %(levelname)-8s - %(message)s")

    ch = logging.StreamHandler()
    ch.setFormatter(log_format)
    log.addHandler(ch)

    fh = logging.handlers.RotatingFileHandler(get_install_dir() + '/post.log', maxBytes=(1024*1024), backupCount=7)
    fh.setFormatter(log_format)
    log.addHandler(fh)

    args = parser.parse_args()

    # as this program gets run separately, if there is a network error 
    # lots can end up running, killing the Yun by eating memory
    file = "/tmp/post.lock"
    fd = open(file, 'w')
    try:
        fcntl.lockf(fd, fcntl.LOCK_EX | fcntl.LOCK_NB)
        log.debug("checked lock ok")
    except IOError:
        log.debug("another process is running with lock. quitting!")
        exit(1)

    # do everything in a try so we can log exceptions
    try:
        if args.auth_token:
            if not args.spread_key:
                parser.error("--auth-token requires --spread-key")
            get_tokens()
        
        elif args.update_cache:
            fetch_users()
            fetch_tools()

        elif args.log_tool:
            if not (args.time and args.rfid):
                parser.error("--log-tool requires --time and --rfid")
            name, tools = get_user(args.rfid)
            log_time(args.log_tool, args.time, name, args.rfid)
        
        elif args.log_unknown_rfid:
            log_unknown_rfid(args.rfid)

        log.debug("ending")
        exit(0)

    except socket.gaierror as e:
        log.error("temporary google service failure")
    except socket.error as e:
        log.error("socket err: %s" % e)
    except Exception as e:
        log.exception(e)

    exit(1)

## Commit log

2015-05-13 case model and render
    [case.scad]
2015-05-13 updated for useful case dimensions
    [case.scad]
2015-05-13 IEC on lid
    [case.scad]
2015-05-22 yun schematic
    [case.scad]
2015-05-22 work on radio controlled sockets, schematic and board layout
    [case.scad, hackspace-power-controller.brd, hackspace-power-controller.sch]
2015-05-22 yun pinout
    [hackspace-power-controller.brd, hackspace-power-controller.sch]
2015-05-22 2 switches version
    [case.scad]
2015-05-22 case datasheet
2015-05-22 case update
    [case.scad]
2015-05-28 nice pin pics
2015-05-28 added spi rfid header
    [hackspace-power-controller.brd, hackspace-power-controller.sch]
2015-05-28 better intro para
2015-05-28 updated shortlink
    [hackspace-power-controller.brd, hackspace-power-controller.sch]
2015-05-29 problems with softserial and encoder library so switched to rotary
    [rfid.ino]
2015-05-29 case statement
2015-05-31 nice time printing
2015-06-01 pin defs finalised
    [hackspace-power-controller.brd, hackspace-power-controller.sch]
2015-06-01 option to refresh cache, print id with tool
2015-06-02 flash strings & radio fix
    [power_controller.ino]
2015-06-02 fixed rfid serial that broke with string tidy
    [rfid.ino]
2015-06-05 log and switched to serial rfid
2015-06-06 arduino readme
2015-06-07 fixed a bug where an old rfid stayed stuck in the serial buffer
    [power_controller.ino, rfid.ino]
2015-06-08 new case
    [case.scad]
2015-06-09 pcb layout for single layer
    [hackspace-power-controller.brd, hackspace-power-controller.sch]
2015-06-09 gitignore pdf
    [case.scad]
2015-06-12 placement holes
    [panel.dxf]
2015-06-12 front panel mount
    [frontpanel.dxf]
2015-06-12 smaller cutouts for strength
    [frontpanel.dxf]
2015-06-12 lots of stuff for cutting the panels
    [case.scad]
2015-06-12 rfid vinyl cut
2015-06-12 fix tool update period
    [power_controller.ino]
2015-06-12 case code tidy
    [case.scad]
2015-06-12 fixes for allowing a new user to turn off another users tool
    [auth.ino, lcd.ino, power_controller.ino]
2015-06-15 sounds and encoder wrapping
2015-06-18 changed psu size and added a complete module
    [case.scad]
